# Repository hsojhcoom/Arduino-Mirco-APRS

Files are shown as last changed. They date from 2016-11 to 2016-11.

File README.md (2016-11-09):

# Arduino-Mirco-APRS

This is a design based on the Mircomodem and LibAPRS (links below).I used the design to create my own boards for a cheaper mobile solution. The different boards are designed around the ATMega 328P uC chip, other chips arduino uses will not work without heavy mods to the libraries.

I will contiune to update the PCB files, with new board designs for different radios.

Mircomodem-https://github.com/markqvist/MicroModem
LibAPRS- https://github.com/markqvist/LibAPRS

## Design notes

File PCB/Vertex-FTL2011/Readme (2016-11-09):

This board is designed for the the Vertex-FTL 2011. It is a great radio for APRS, they are cheap and durable.
It uses an RJ45 for the mic, and the board is designed with an RJ45 for direct connections
Along with the TX, the board can hand RX as well, two pads are there to connected a 3.5 jack (female). 

The uC is an Arduino Pro Mini either 5v or 3v3 versions. Along with the uC the board includes a Ublox Neo 6m GPS module.

pcb_eagle_snip

[url=https://flic.kr/p/NSn6vw][img]https://c5.staticflickr.com/6/5803/30762352012_96a7987ef3.jpg[/img][/url][url=https://flic.kr/p/NSn6vw]f59d448a-a605-11e6-9024-55bf624ab5a8[/url] by [url=https://www.flickr.com/photos/77812812@N02/]Pickles_21[/url], on Flickr

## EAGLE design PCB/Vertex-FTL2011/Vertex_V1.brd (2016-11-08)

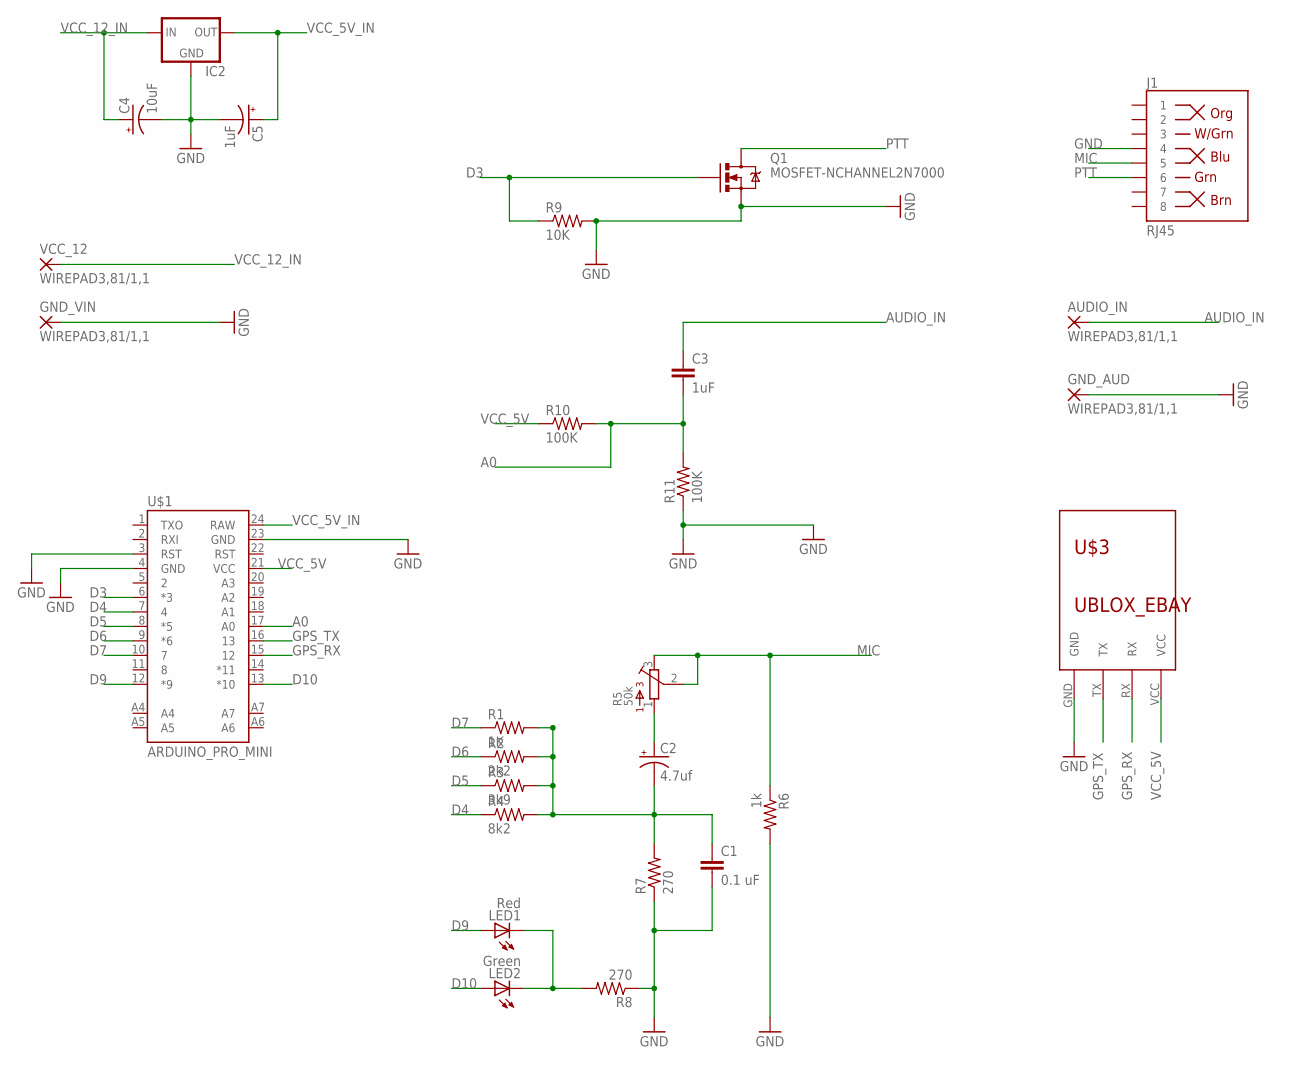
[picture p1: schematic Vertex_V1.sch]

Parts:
AUDIO_IN: WIREPAD3,81/1,1; 3,81/1,1
C1: 0.1 uF; CAP-PTH-SMALL-KIT
C2: 4.7uf; CPOL-RADIAL-10UF-25V
C3: 1uF; CAP-PTH-SMALL-KIT
C4: 10uF; CPOL-RADIAL-10UF-25V
C5: 1uF; CPOL-RADIAL-10UF-25V
GND_AUD: WIREPAD3,81/1,1; 3,81/1,1
GND_VIN: WIREPAD3,81/1,1; 3,81/1,1
IC2: 78XXS
J1: RJ45; RJ45-8
LED1: Red; LED5MM
LED2: Green; LED5MM
Q1: MOSFET-NCHANNEL2N7000; TO-92
R1: 1K; 0309V
R2: 2k2; 0309V
R3: 3k9; 0309V
R4: 8k2; 0309V
R5: 50k; 3362P
R6: 1k; 0309V
R7, R8: 270; 0309V
R9: 10K; 0309V
R10, R11: 100K; 0309V
U$1: ARDUINO_PRO_MINI
U$3: UBLOX_EBAY
VCC_12: WIREPAD3,81/1,1; 3,81/1,1

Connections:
A0: C3.2, R10.2, R11.2, U$1.17 (A0)
AUDIO_IN: AUDIO_IN.1, C3.1
D3: Q1.2 (G), R9.1, U$1.6 (*3)
D4: R4.1, U$1.7 (4)
D5: R3.1, U$1.8 (*5)
D6: R2.1, U$1.9 (*6)
D7: R1.1, U$1.10 (7)
D9: LED1.A, U$1.12 (*9)
D10: LED2.A, U$1.13 (*10)
GND: C1.2, C4.2 (-), C5.2 (-), GND_AUD.1, GND_VIN.1, IC2.GND, J1.4, Q1.1 (S), R6.2, R7.1, R8.1, R9.2, R11.1, U$1.3 (RST), U$1.4 (GND), U$1.23 (GND), U$3.GND
GPS_RX: U$1.15 (12), U$3.RX
GPS_TX: U$1.16 (13), U$3.TX
MIC: J1.5, R5.2, R5.3, R6.1
unnamed: C1.1, C2.2 (-), R1.2, R2.2, R3.2, R4.2, R7.2
unnamed: C2.1 (+), R5.1
unnamed: LED1.K (C), LED2.K (C), R8.2
PTT: J1.6, Q1.3 (D)
VCC_5V: R10.1, U$1.21 (VCC), U$3.VCC
VCC_5V_IN: C5.1 (+), IC2.OUT, U$1.24 (RAW)
VCC_12_IN: C4.1 (+), IC2.IN, VCC_12.1

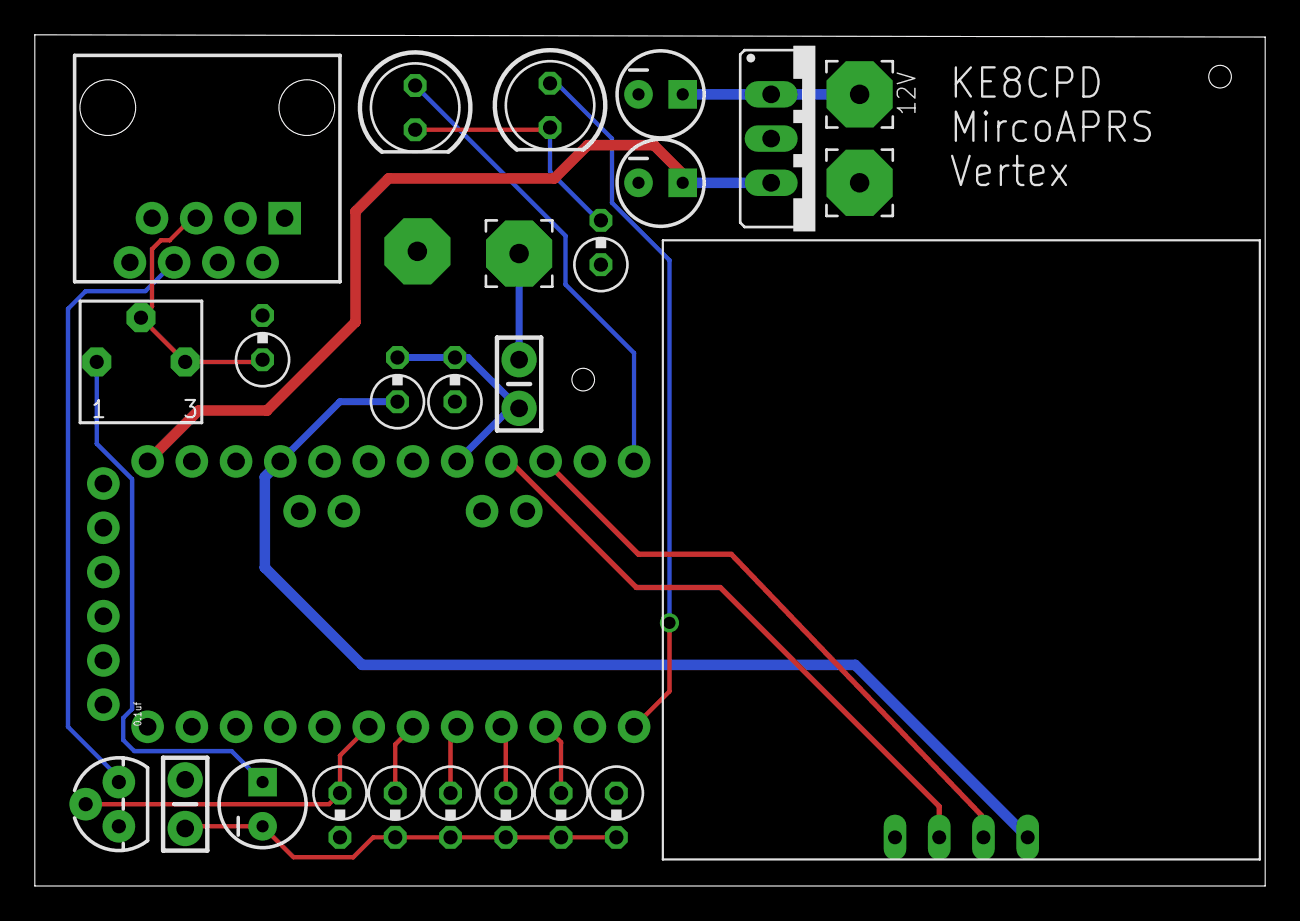
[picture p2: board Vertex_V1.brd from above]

Board: 2 copper layers, 70.7 x 48.9 mm, 27 parts (1 on the bottom side), 20 nets.

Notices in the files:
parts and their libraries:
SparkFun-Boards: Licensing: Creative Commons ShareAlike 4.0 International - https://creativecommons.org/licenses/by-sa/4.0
